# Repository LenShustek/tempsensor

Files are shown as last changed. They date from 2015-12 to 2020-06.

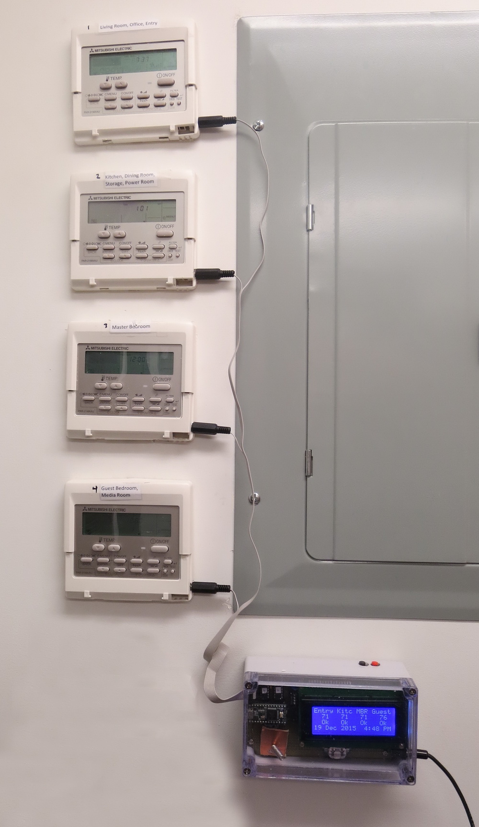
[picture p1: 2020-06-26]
temprcvr_V2/complete_installation.JPG

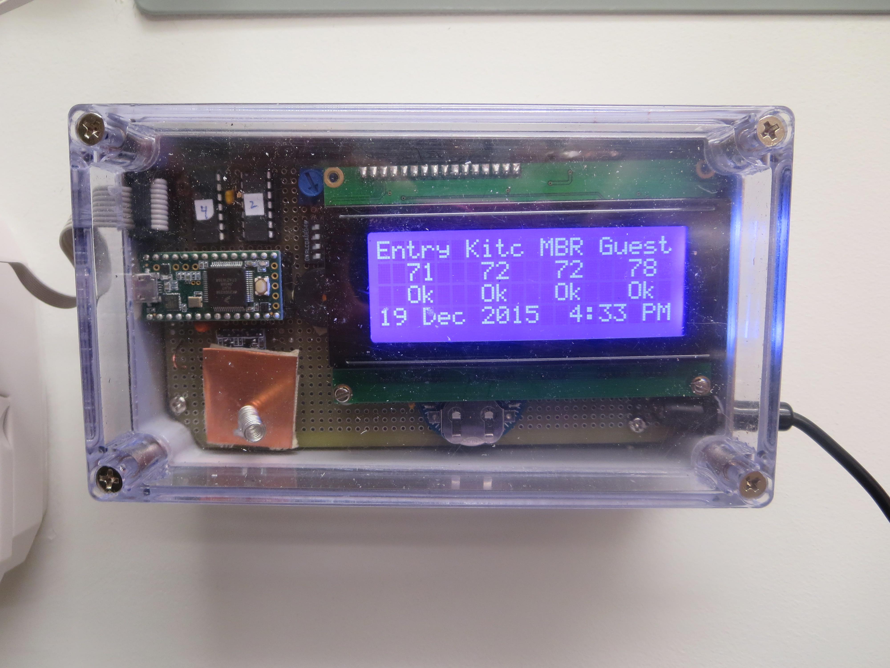
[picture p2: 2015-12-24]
[Originals]/receiver_box_02.JPG

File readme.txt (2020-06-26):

This project consists of four small battery-powered remote wireless temperature sensors, and a single wall-powered receiver for them that replaces the temperature-monitoring thermistors inside wall-mounted thermostats.

My motivation: we have a four-zone Mitsubishi/Honeywell MNET-based HVAC system that was incorrectly designed without temperature monitoring in the zones. We want to avoid breaking walls and ceilings to wire compatible themostats. The Honeywell C7189 wireless indoor remote temperature sensor is not compatible, and we don't like the complicated Mitsubishi MRCH1 wireless remote controller because it's big, ugly, and conflicts with the automation system (Control4) that is supposed to be in control of all the HVAC zones.

This project reinstates the four centrally located wired wall-mounted PAR-21MAA thermostats that were part of the original design, but replaces their temperature-sensing thermistors with resistances generated by "digital potentiometers" controlled by an Arduino-like microprocessor. The wireless remote temperature sensors send periodic wireless packets to the central receiver. The indoor range is several hundred feet.

The first version of the system -- which used an LCD display, the Seeed HC-12 433 Mhz transceiver, and a Teensy LC processor -- was installed in December 2015 and worked well for years. The only annoying issue was that with the best low-power code I could muster, the lifetime of the three AAA batteries in each temperature sensor was only 2-3 months.

That prompted me to make a second version of the temperature sensor that uses an e-Paper display, a HopeRF LoRa 868/915 Mhz transceiver, and a bare ATMega328 processor. The average power utilization is now below 100 uA, which resulted in battery life of well over a year.

Unfortunately Waveshare decided to redesign their e-paper module to be 5V compatible, and the resulting quiescent power drain from the voltage regulator and level shifters destroys the "zero current when sleeping" feature that made me choose e-paper displays in the first place. In addition, some of their older modules are defective and use 100 mA when updating the display instead of the specified 12 mA maximum, which puts battery life back to months, not years. 

That prompted me to make a third version that uses just the raw e-paper display, not the module. It was also an opportunity to exercise my newly-learned skills of designing and fabricating boards with only surface-mount components. The average power utilization is now about 60 uA, so the batteries last almost two years.

Len Shustek
Nov 2015, Jul 2018, Jun 2020

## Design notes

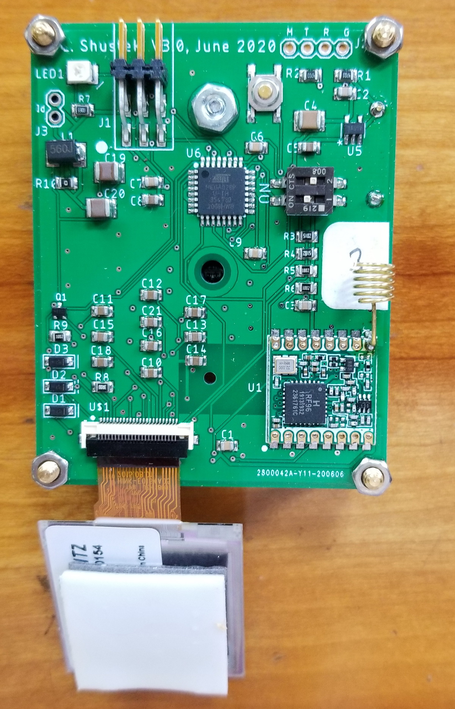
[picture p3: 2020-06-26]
tempsensor_V3/inside.jpg

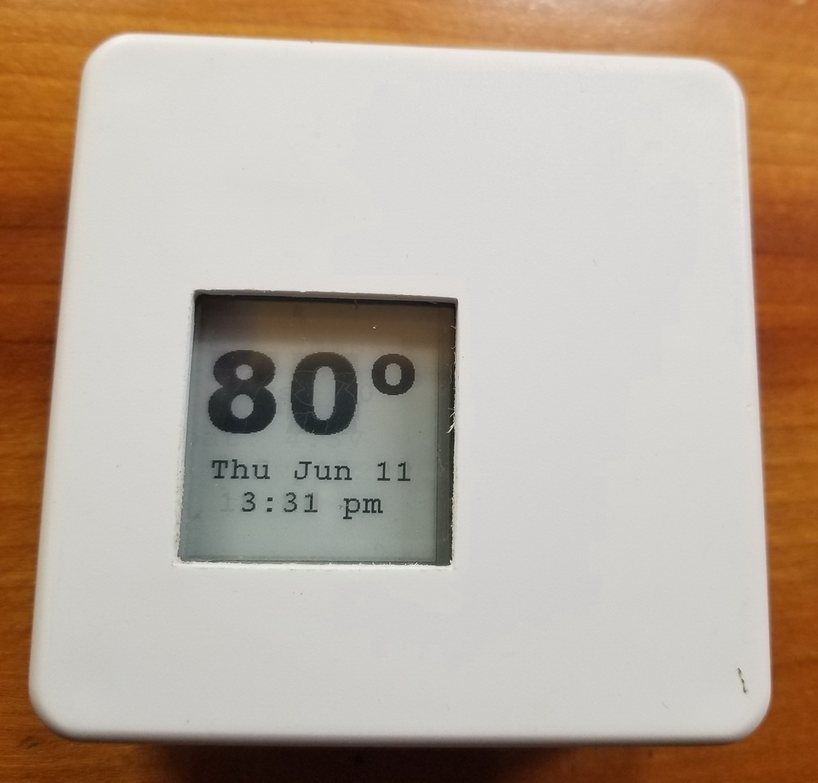
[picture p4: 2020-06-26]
tempsensor_V3/outside.jpg

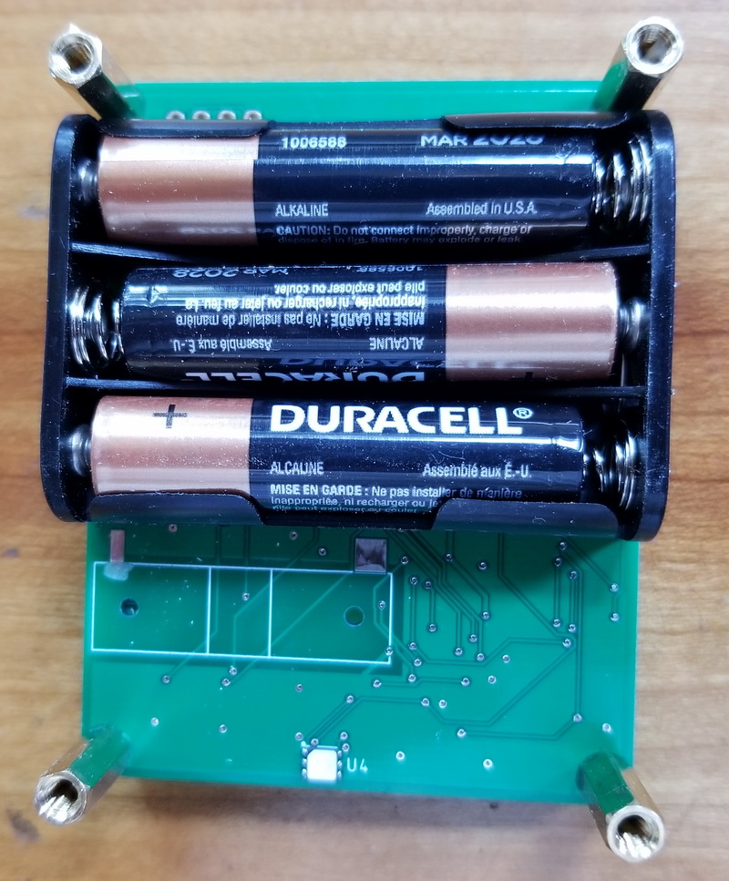
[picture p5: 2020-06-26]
tempsensor_V3/bottom.jpg

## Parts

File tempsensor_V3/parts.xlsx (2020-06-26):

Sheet: parts
 |  | Tempsensor V3.0 parts
# per unit | # for all units | have | order | descr | for | ref | manuf | manuf p/n | vendor | vendor p/n | price each
1 | 5 | 4 |  | 4xAAA battery holder |  | B1 | Keystone | 2479 | Mouser | 534-2479 | $1.61
5 | 25 |  | 100 | 0.1 ufd 50V X7R SMD 0805 capacitor |  | C1,C2,C3,C7,C9 | Kemet | C0805C104K5RACTU | Mouser | 80-C0805C104K5R | $0.06
1 | 5 |  | 10 | 4.7 ufd 50V X7R SMD 1210 capacitor |  | C19 | Kemet | C1210C475K5RAC | Mouser | 80-C1210C475K5RAC | $0.48
1 | 5 | 5 | 10 | 10 ufd 25V X7R SMD 1210 capacitor |  | C20 | Kemet | C1210C106M3RACTU | Mouser | 80-C1210C106M3R | $0.39
1 | 5 |  | 10 | 2.2 ufd 50V X7R SMD 1210 capacitor |  | C4 | Kemet | C1210C225K5RACTU | Mouser | 80-C1210C225K5R | $0.45
12 | 60 |  | 100 | 1.0 ufd 50V X7R SMD 0805 capacitor |  | C5,C8,C10-18,C21 | Kemet | C0805C105K5RACTU | Mouser | 80-C0805C105K5R | $0.17
1 | 5 |  | 100 | .047ufd 50V SMD 0805 capacitor |  | C6 | Kemet | C0805C473K5RACTU | Mouser | 80-C0805C473K5R | $0.06
3 | 15 |  | 100 | MBR0530 Schottky diode |  | D1,D2,D3 | ON Semi | MBR0530T1G | Mouser | 863-MBR0530T1G | $0.08
~~1~~ | ~~5~~ |  | ~~20~~ | ~~2x6 SMD pin header 0.1" vertical~~ | ~~programming~~ | ~~J1~~ | ~~molex~~ | ~~15-91-0060~~ | ~~Mouser~~ | ~~538-15-91-0060~~ | ~~$0.35~~
1 | 5 |  | 10 | 2x6 SMD pin header 0.1" rt angle | programming | J2 | Samtec | TSM-103-01-S-DH-TR TSM-103-01-L-DH | Mouser Digikey | 200-TSM10301SDHTR SAM9026-ND | 1.48 0.88
1 | 5 | lots |  | 1x3 through hole pin header 0.1" | debugging | J2
1 | 5 | 18 |  | 56 uH inductor SMD 1812 | filter | L1 | Bourns | PM1812-560J-RC | Mouser | 542-PM1812-560J-RC | $0.31
1 | 5 |  | 25 | red LED, SMD PLCC-2, flat top, 2mm high |  | LED1 | OSRAM | LS T67F-T2V2-1-1-Z | Mouser | 720-LST67FT2V211Z | $0.27
1 | 5 |  | 25 | Si1308 N-channel MOSFET |  | Q1 | Vishay | SI1308EDL-T1-GE3 | Mouser Digikey | 78-SI1308EDL-T1-GE3 SI1308EDL-T1-GE3CT-ND | $0.45
2 | 10 | some |  | 470K 1% 1/8W SMD 0805 resistor |  | R1,R2
2 | 10 | some |  | 51K 1% 1/8W SMD 0805 resistor |  | R3,R4
3 | 15 | some |  | 10K 1% 1/8W SMD 0805 resistor |  | R5,R6,R9
1 | 5 | some |  | 330 ohm 1% 1/8W SMD 0805 resistor |  | R7
1 | 5 | some |  | 3 ohm 1% 1/8W SMD 0805 resistor |  | R8
1 | 5 |  | 10 | 2-position SPST slide switch, gull wing SMD | node address | SW2 | CTS | 219-2MSTRF | Mouser | 774-2192MSTRF | $0.62
1 | 5 |  | 10 | FPC connector, 24-pin, SMD, bottom contact |  | U$1 | Molex | 505110-2491 | Mouser | 538-505110-2491 | $0.71
1 | 5 |  | 2 | RFM95 RF 868 Mz radio transceiver |  | U1 | Seeed | 109990166 | Seeed Digikey | 109990166 1597-1488-ND | 6.95 7.09
1 | 5 |  | 5 | Si7021-A20 temperature/humidity sensor |  | U4 | Silicon Labs | SI7021-A20-IM1 | Mouser | 634-SI7021-A20-IM1 | $3.53
1 | 5 | 13 |  | MCP1711 3.3V voltage regulator |  | U5 | Microchip | MCP1711T-33I/OT | Mouser | 579-MCP1711T-33I/OT | $0.37
1 | 5 | 2 | 10 | ATMega328P processor, SMD TQFP-44 |  | U6 | Microchip | ATMEGA328P-AUR | Mouser Digikey | 556-ATMEGA328P-AUR ATMEGA328P-AURCT-ND | $1.73
1 | 5 |  | 5 | 1.54" e-paper B/W display |  |  | Crystalfonz Waveshare | CFAP200200A1-0154 1`2955 | Crystalfonz Waveshare |  | 12.64 12.99 | https://www.amazon.com/Waveshare-Resolution-Electronic-Controller-Interface/dp/B071HW4Z6N
1 | 5 |  | 5 | 868 Mhz helical antenna |  |  | PulseLarsen Ants | W3136 | Digikey | 1837-1134-2-ND | $1.36
1 | 5 |  | 25 | pushbutton, SPST mom, gullwing SMT |  |  | C&K | PTS525SM15SMTR2 LFS | Digikey | CKN9104CT-ND | $0.32
5 | units to build

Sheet: total current
8 | 0.071
8.002 | 0.051
8.004 | 0.031
8.006 | -0.009
8.008 | 0.071
8.01 | 0.011
8.012 | -0.009
8.014 | 0.051
8.016 | 0.011
8.018 | 0.051
8.02 | 0.051
8.022 | 0.031
8.024 | 0.051
8.026 | 0.031
8.028 | 0.031
8.03 | 0.051
8.032 | 0.011
8.034 | 0.091
8.036 | 1.491
8.038 | 0.591
8.04 | 0.871
8.042 | 0.981
8.044 | 1.001
8.046 | 0.921
8.048 | 0.961
8.05 | 0.961
8.052 | 0.961
8.054 | 1.041
8.056 | 0.921
8.058 | 0.921
8.06 | 0.921
8.062 | 0.981
8.064 | 0.961
8.066 | 0.961
8.068 | 0.921
8.07 | 0.961
8.072 | 1.021
8.074 | 1.861
8.076 | 19.521
8.078 | 17.461
8.08 | 16.921
8.082 | 16.591
8.084 | 16.221
8.086 | 15.961
8.088 | 15.591
8.09 | 15.361
8.092 | 15.281
8.094 | 14.991
8.096 | 14.871
8.098 | 14.541
8.1 | 14.501
8.102 | 14.451
8.104 | 22.831
8.106 | 22.191
8.108 | 22.011
8.11 | 21.451
8.112 | 21.101
8.114 | 20.751
8.116 | 20.501
8.118 | 20.321
8.12 | 20.071
8.122 | 2.851
8.124 | 1.991
8.126 | 2.751
8.128 | 2.011
8.13 | 2.871
8.132 | 2.811
8.134 | 1.641
8.136 | 1.611
8.138 | 1.371
8.14 | 2.131
8.142 | 0.941
8.144 | 1.991
8.146 | 2.831
8.148 | 3.061
8.15 | 3.121
8.152 | 2.231
8.154 | 3.801
8.156 | 2.731
8.158 | 3.181
8.16 | 3.161
8.162 | 2.641
8.164 | 4.081
8.166 | 3.201
8.168 | 2.071
8.17 | 2.051
8.172 | 3.011
8.174 | 2.771
8.176 | 2.731
8.178 | 2.771
8.18 | 2.151
8.182 | 3.491
8.184 | 1.821
8.186 | 2.171
8.188 | 2.641
8.19 | 2.641
8.192 | 2.731
8.194 | 4.371
8.196 | 2.501
8.198 | 3.511
8.2 | 2.311
8.202 | 1.861
8.204 | 3.801
8.206 | 4.451
8.208 | 2.831
8.21 | 2.071
8.212 | 2.811
8.214 | 2.461
8.216 | 3.471
8.218 | 3.381
8.22 | 3.061
8.222 | 4.191
8.224 | 3.571
8.226 | 3.921
8.228 | 2.401
8.23 | 2.931
8.232 | 1.451
8.234 | 2.151
8.236 | 2.971
8.238 | 2.851
8.24 | 3.861
8.242 | 0.831
8.244 | 4.171
8.246 | 2.991
8.248 | 2.291
8.25 | 2.561
8.252 | 3.341
8.254 | 3.451
8.256 | 0.261
8.258 | 2.361
8.26 | 2.681
8.262 | 3.181
8.264 | 2.601
8.266 | 3.061
8.268 | 3.411
8.27 | 1.681
8.272 | 2.031
8.274 | 1.491
8.276 | 1.781
8.278 | 2.911
8.28 | 3.511
8.282 | 4.131
8.284 | 2.601
8.286 | 4.151
8.288 | 3.201
8.29 | 3.631
8.292 | 3.181
8.294 | 2.441
8.296 | 3.571
8.298 | 3.141
8.3 | 3.321
8.302 | 5.011
8.304 | 2.361
8.306 | 2.341
8.308 | 2.991
8.31 | 2.851
8.312 | 3.061
8.314 | 1.901
8.316 | 2.231
8.318 | 2.681
8.32 | 2.621
8.322 | 2.731
8.324 | 3.361
8.326 | 2.621
8.328 | 0.301
8.33 | 3.141
8.332 | 3.221
8.334 | 2.541
8.336 | 2.641
8.338 | 3.881
8.34 | 2.311
8.342 | 2.111
8.344 | 3.141
8.346 | 2.171
8.348 | 2.731
8.35 | 4.131
8.352 | 3.301
8.354 | 4.641
8.356 | 3.281
8.358 | 4.391
8.36 | 1.881
8.362 | 3.011
8.364 | 2.561
8.366 | 2.481
8.368 | 3.861
8.37 | 1.821
8.372 | 3.671
8.374 | 2.971
8.376 | 2.641
8.378 | 2.601
8.38 | 2.771
8.382 | 2.561
8.384 | 1.271
8.386 | 1.941
8.388 | 3.591
8.39 | 2.621
8.392 | 3.801
8.394 | 3.081
8.396 | 2.871
8.398 | 1.451
8.4 | 1.551
8.402 | 3.431
8.404 | 3.341
8.406 | 2.421
8.408 | 2.441
8.41 | 3.491
8.412 | 2.731
8.414 | 3.181
8.416 | 2.231
8.418 | 2.641
8.42 | 3.141
8.422 | 3.201
8.424 | 2.521
8.426 | 3.011
8.428 | 5.071
8.43 | 0.671
8.432 | 0.921
8.434 | 0.871
8.436 | 1.861
8.438 | 1.061
8.44 | 1.081
8.442 | 0.541
8.444 | 0.051
8.446 | 3.201
8.448 | 0.461
8.45 | 1.201
8.452 | 0.921
8.454 | 1.161
8.456 | 1.331
8.458 | 0.011
8.46 | 0.011
8.462 | 0.031
8.464 | 0.051
8.466 | 0.011
8.468 | -0.009
8.47 | 0.031
8.472 | 0.051
8.474 | -0.009
8.476 | 0.031
8.478 | -0.009
8.48 | -0.009
8.482 | 0.031
8.484 | 0.011
8.486 | 0.011
8.488 | -0.009
8.49 | -0.009
8.492 | 0.011
8.494 | -0.009
8.496 | 0.011
8.498 | 0.051

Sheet: epaper displays
1.54" e-paper modules
 |  |  |  | in stock | delivery
MikroElektronika | MIKROE-3157 | Digikey | 1471-2067-ND | 9 | 1 week | $20.79
Waveshare |  | Amazon | B071HW4Z6N | ? | 6 weeks | $12.99
CystalFontz | CFAP200200A1-0154 | CystalFontz |  | ? | 1 week | $12.64
Pervasive Displays | E2154CS091 | Digikey | E2154CS091-ND | 346 | 1 week | $6.80 | short tab

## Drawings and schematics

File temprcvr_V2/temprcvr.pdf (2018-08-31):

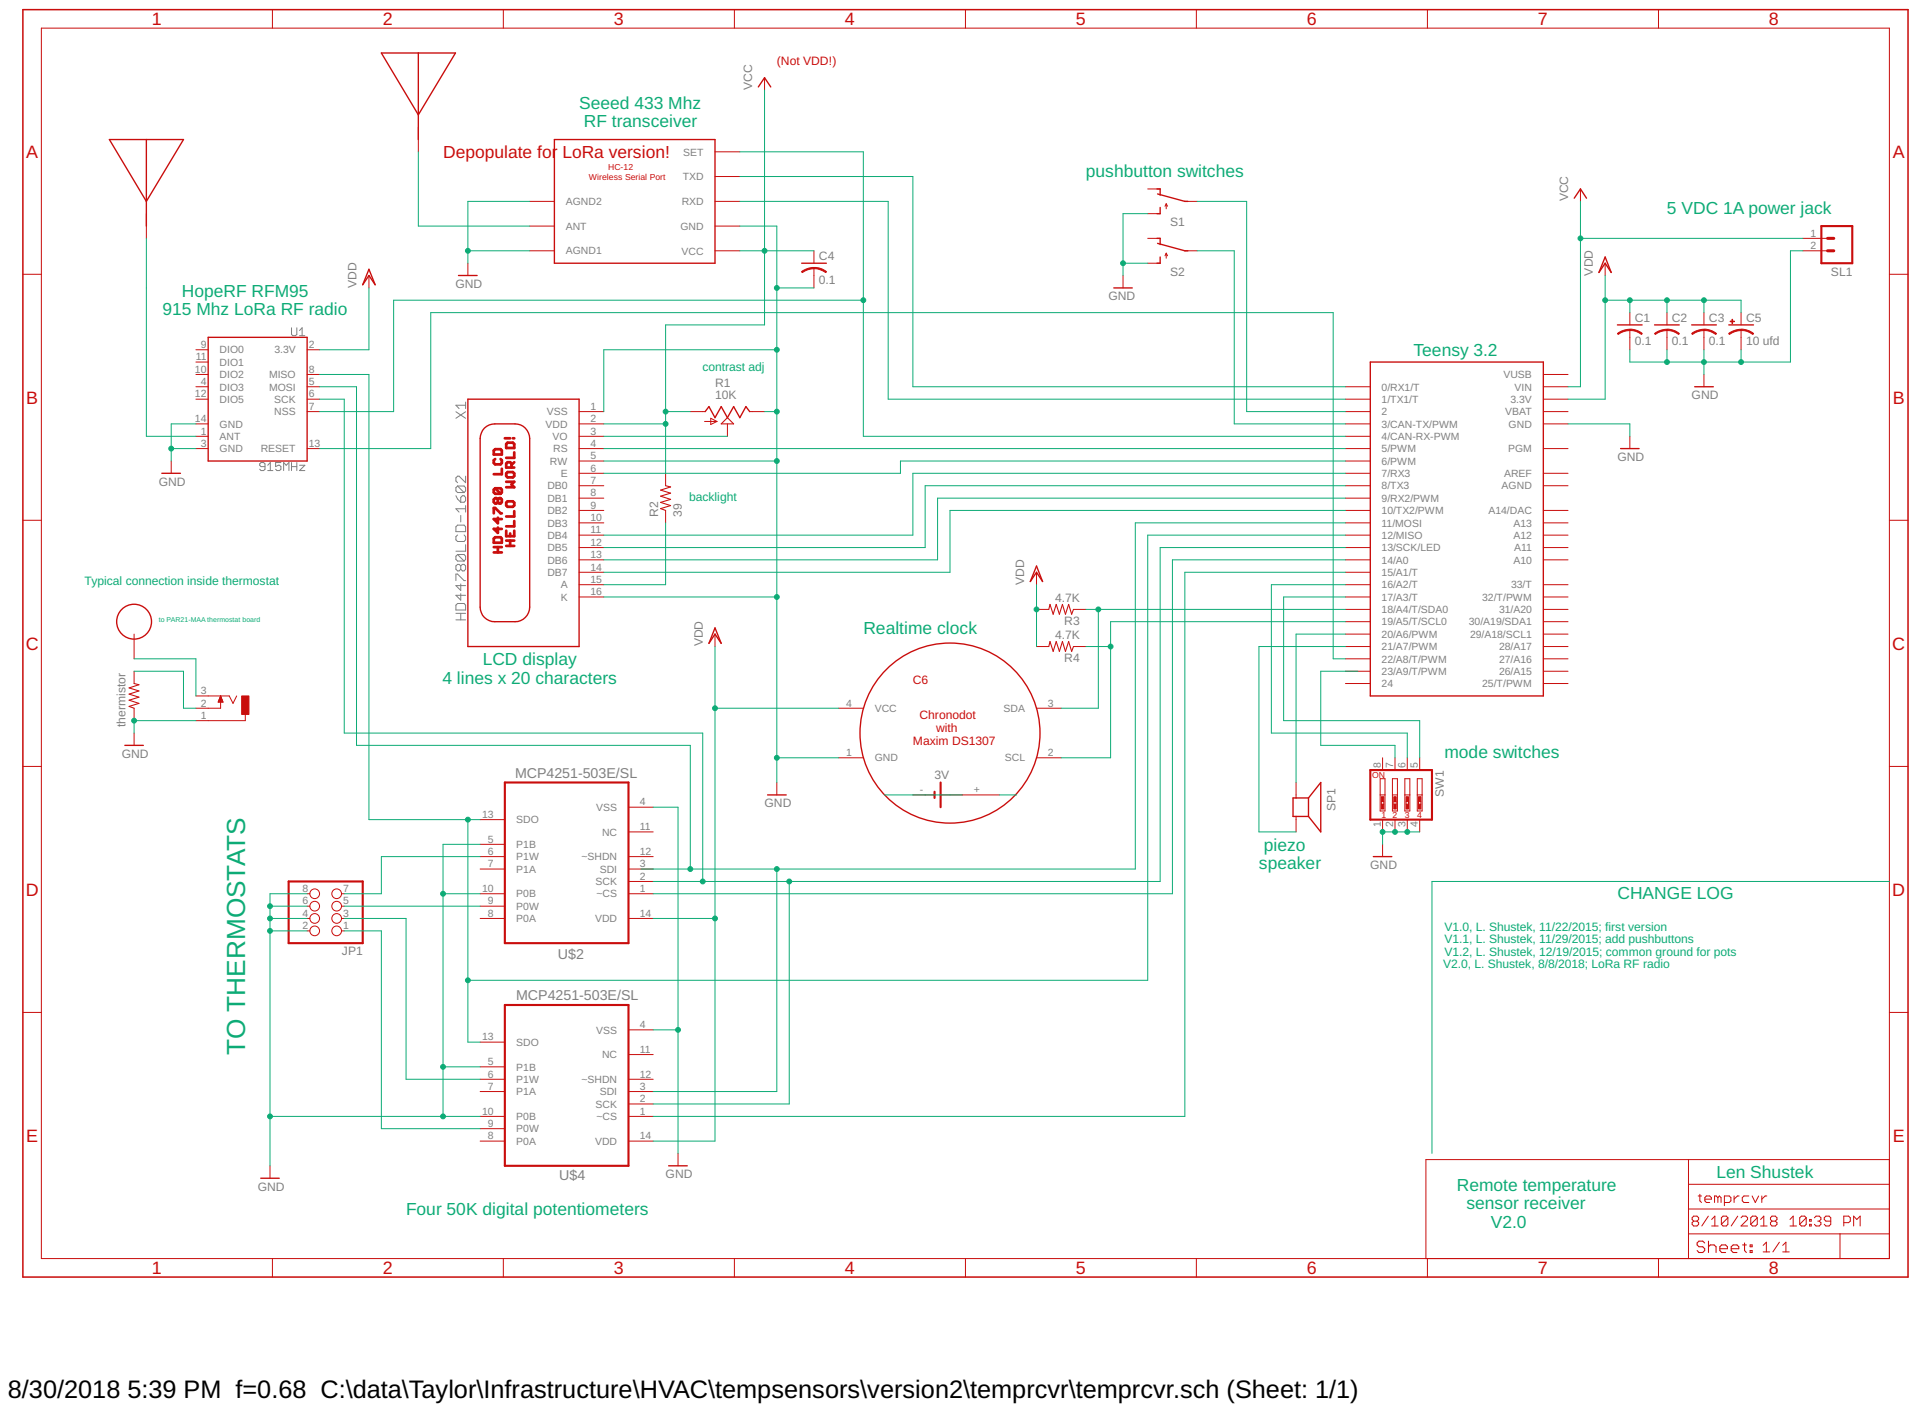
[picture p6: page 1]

Seeed 433 Mhz RF transceiver

Depopulate for LoRa version! HC-12 Wireless Serial Port A

HopeRF RFM95
915 Mhz LoRa RF radio

12 DB4
13 DB5
14 DB6
15 DB7

to PAR21-MAA thermostat board Typical connection inside thermostat

1 2 3 4 ON Chronodot with Maxim DS1307 C6

V1.0, L. Shustek, 11/22/2015; first version
V1.1, L. Shustek, 11/29/2015; add pushbuttons V1.2, L. Shustek, 12/19/2015; common ground for pots

V2.0, L. Shustek, 8/8/2018; LoRa RF radio

8/30/2018 5:39 PM f=0.68 C:\data\Taylor\Infrastructure\HVAC\tempsensors\version2\temprcvr\temprcvr.sch (Sheet: 1/1)

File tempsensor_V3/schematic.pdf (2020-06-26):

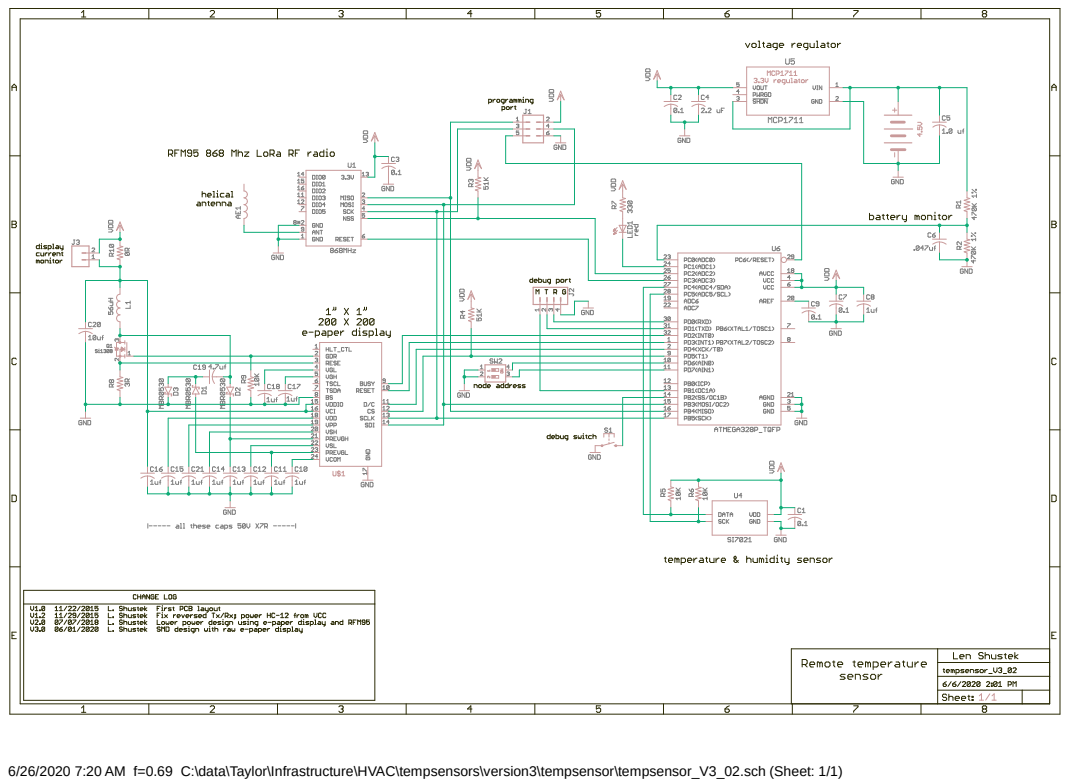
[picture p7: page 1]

6/26/2020 7:20 AM f=0.69 C:\data\Taylor\Infrastructure\HVAC\tempsensors\version3\tempsensor\tempsensor_V3_02.sch (Sheet: 1/1)

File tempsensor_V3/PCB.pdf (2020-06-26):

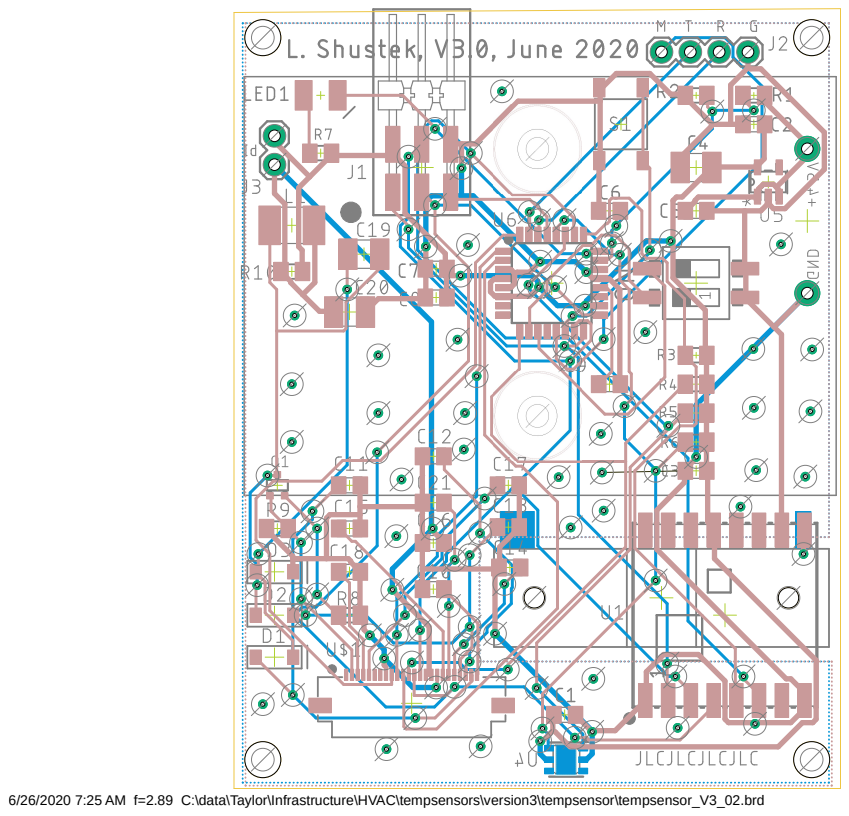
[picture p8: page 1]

6/26/2020 7:25 AM f=2.89 C:\data\Taylor\Infrastructure\HVAC\tempsensors\version3\tempsensor\tempsensor_V3_02.brd

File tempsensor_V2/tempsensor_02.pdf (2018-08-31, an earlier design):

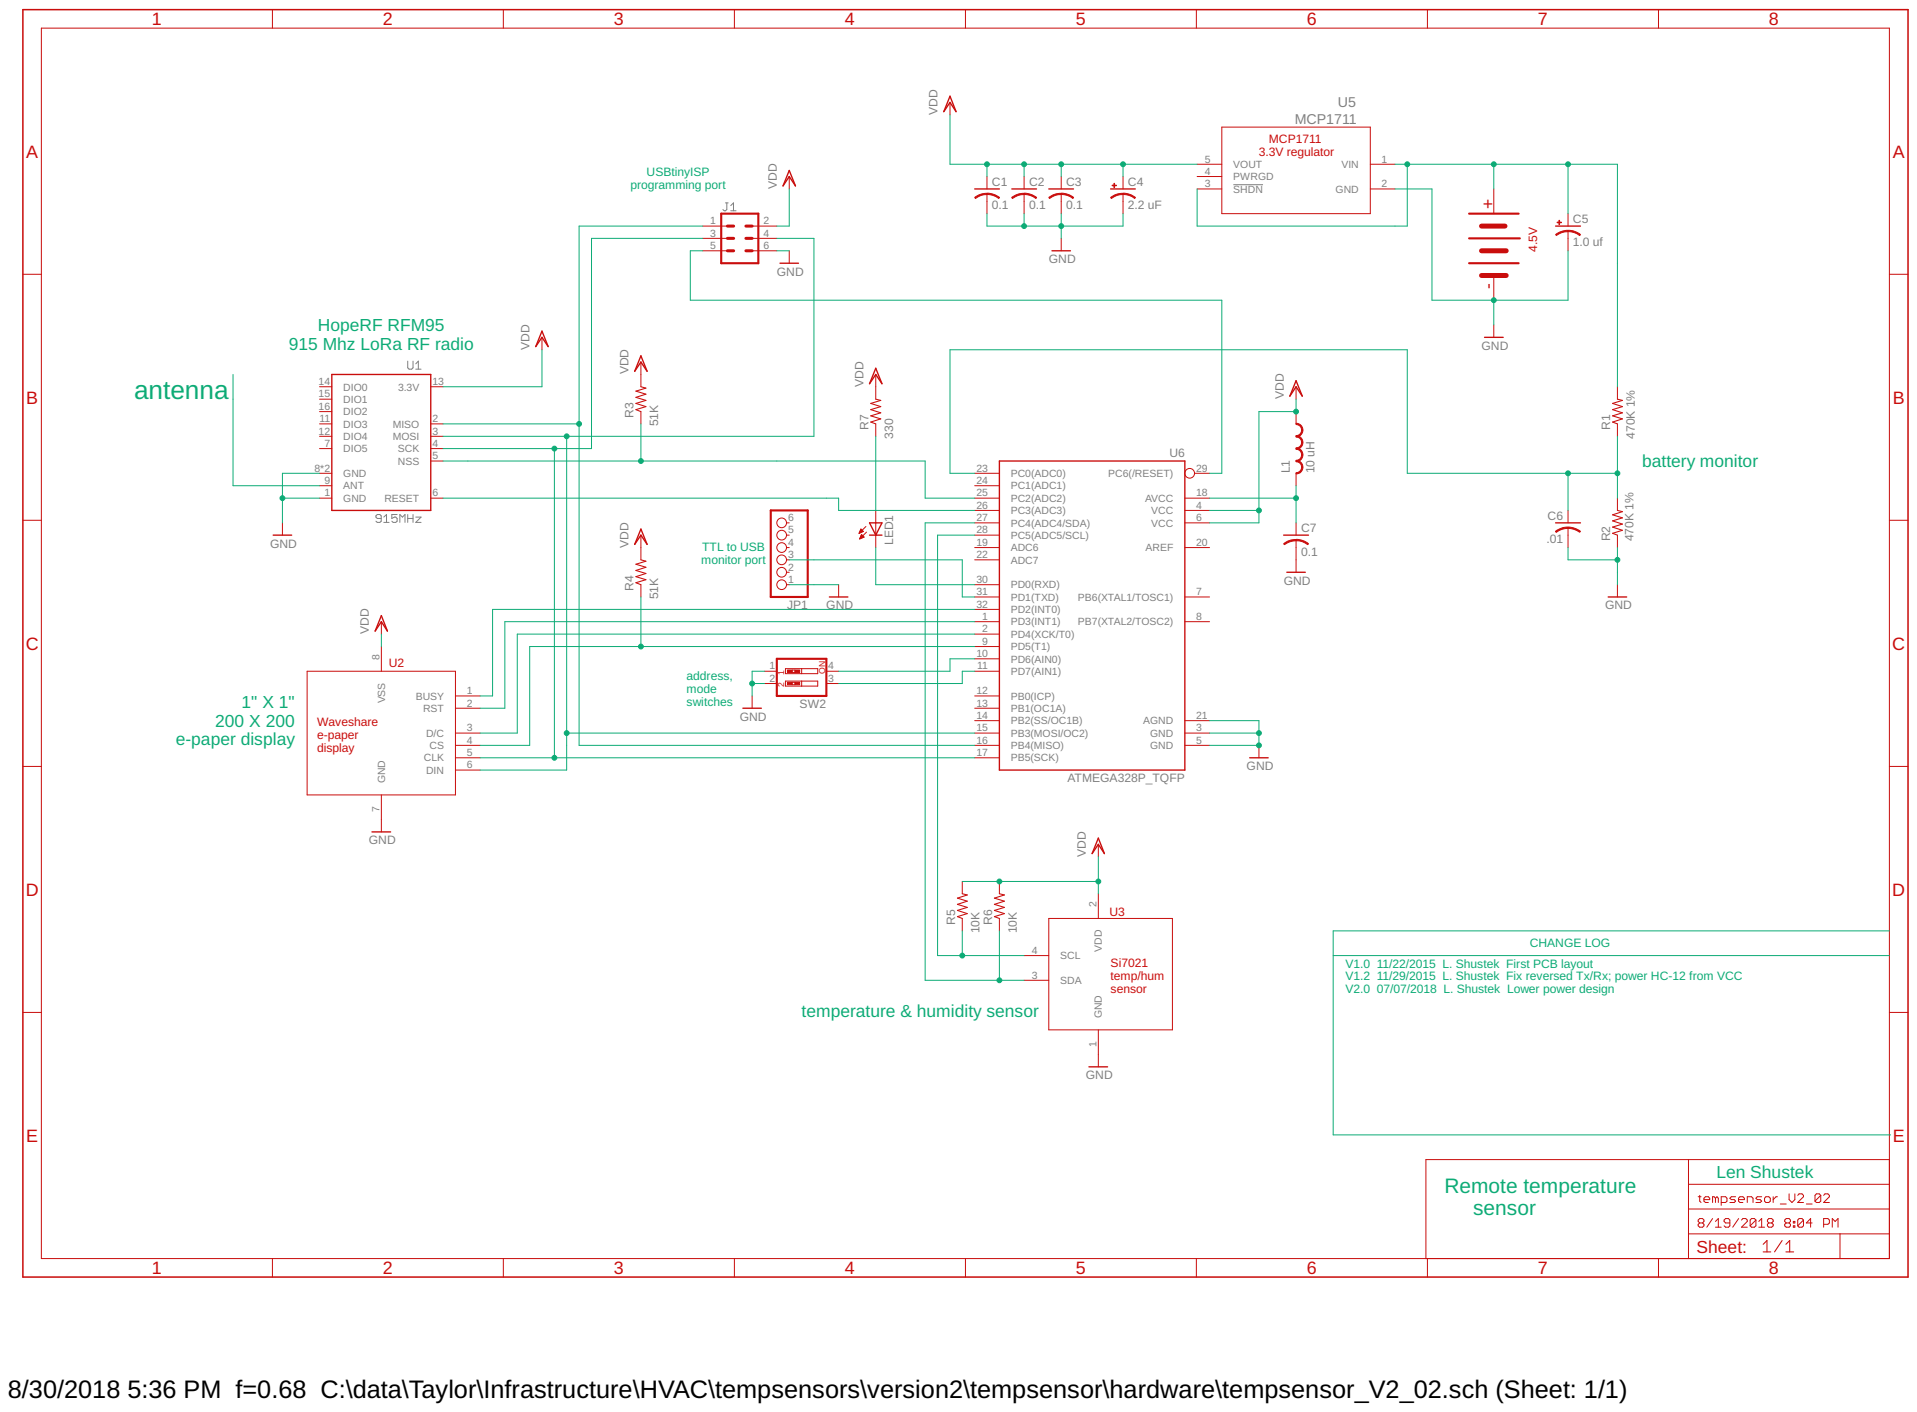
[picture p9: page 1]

HopeRF RFM95
915 Mhz LoRa RF radio

TTL to USB monitor port

4 D/C | | 3 GND 5

5 CS | PB5(SCK) 17
6 CLK

V1.0 11/22/2015 L. Shustek First PCB layout CHANGE LOG

V1.2 11/29/2015 L. Shustek Fix reversed Tx/Rx; power HC-12 from VCC
V2.0 07/07/2018 L. Shustek Lower power design

8/30/2018 5:36 PM f=0.68 C:\data\Taylor\Infrastructure\HVAC\tempsensors\version2\tempsensor\hardware\tempsensor_V2_02.sch (Sheet: 1/1)

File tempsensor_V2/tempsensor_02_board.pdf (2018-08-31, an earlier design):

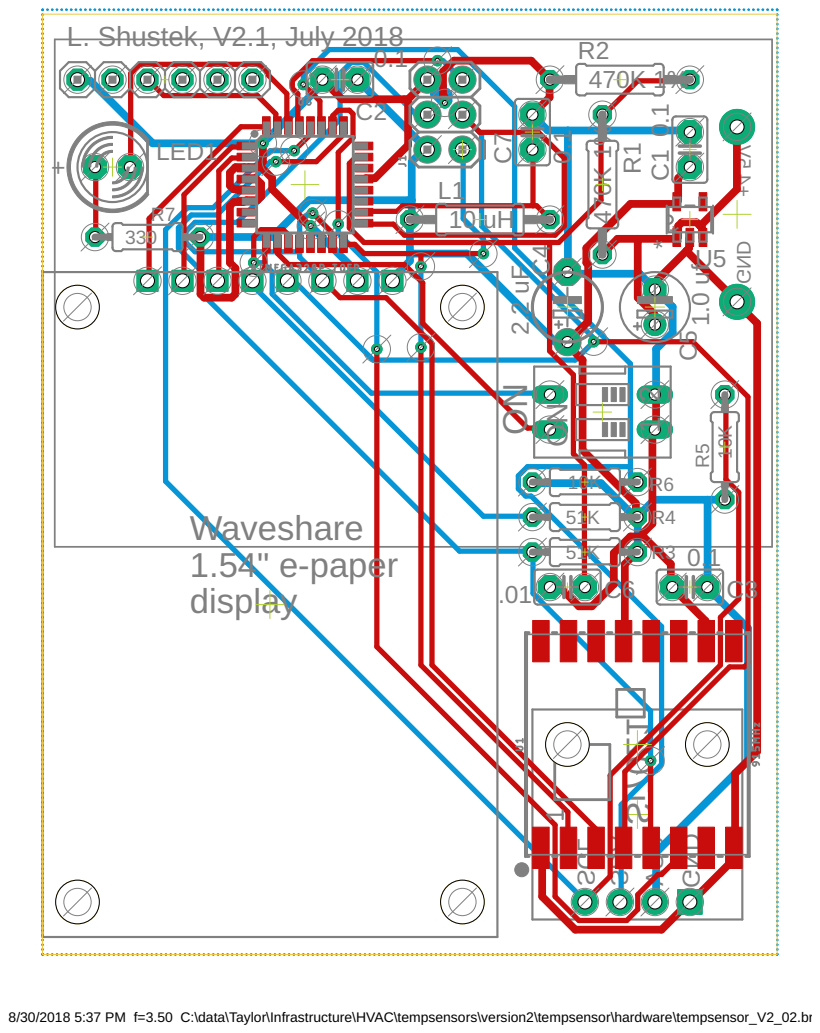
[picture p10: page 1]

8/30/2018 5:37 PM f=3.50 C:\data\Taylor\Infrastructure\HVAC\tempsensors\version2\tempsensor\hardware\tempsensor_V2_02.brd

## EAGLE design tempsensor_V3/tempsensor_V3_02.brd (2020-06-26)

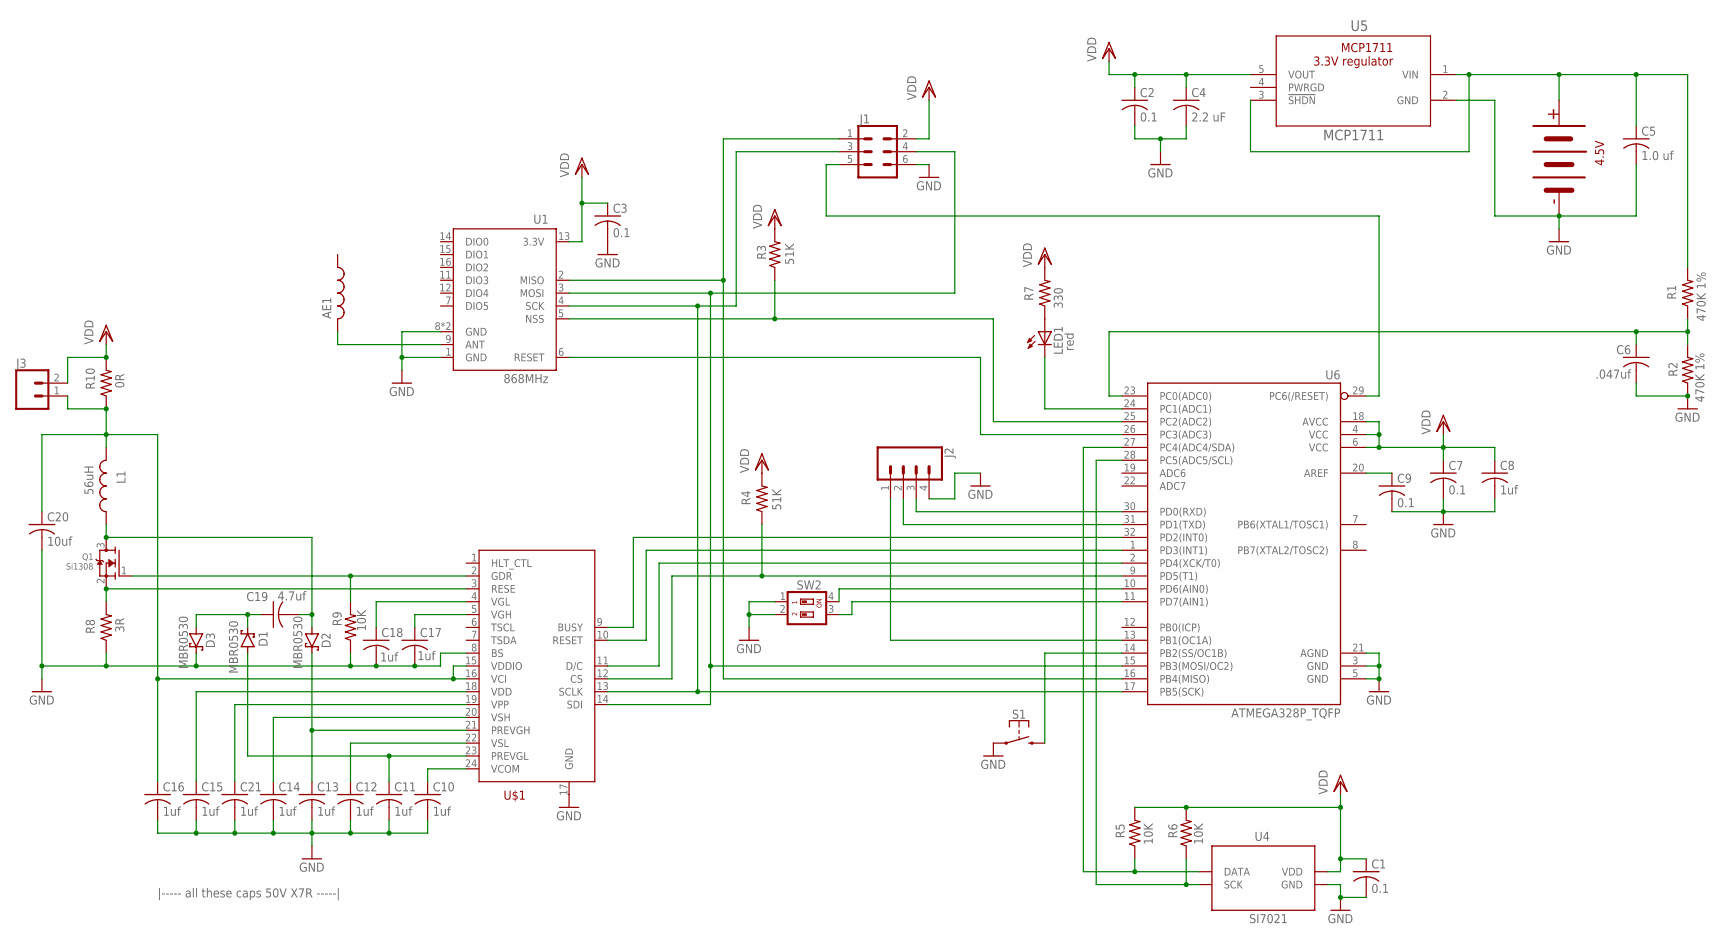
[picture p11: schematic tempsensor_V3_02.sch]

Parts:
AE1: ANTENNA-HELICAL; ANTENNA-HELICAL_PULSE_SMD
B1: 3PC-BATTERY-HOLDER; 3AAA-BATTERY-HOLDER
C1, C2, C3, C7, C9: 0.1; C0805
C4: 2.2 uF; C1210
C5: 1.0 uf; C0805
C6: .047uf; C0805
C8, C10, C11, C12, C13, C14, C15, C16, C17, C18, C21: 1uf; C0805
C19: 4.7uf; C1210
C20: 10uf; C1210
D1, D2, D3: MBR0530; SOD123-2
J1: CONN_2X3; 2X3_SMT_RTANGLE_OUTLINE
J2: CONN_04; 1X04
J3: CONN_02; 1X02
L1: 56uH; L1812
LED1: red; LED_PLCC-2
Q1: Si1308; SC70-3-R
R1, R2: 470K 1%; M0805
R3, R4: 51K; M0805
R5, R6, R9: 10K; M0805
R7: 330; M0805
R8: 3R; M0805
R10: 0R; M0805
S1: PUSHBUTTON-SPSTSWITCH_C&K_GULLWING_5MM; SWITCH_C&K_GULLWING_5MM
SW2: SWITCH-2POS-DIP; SMS-002
U1: 868MHz; RFM69HCW-XXXS2
U4: SI7021; DFN-6-3X3-SI7021
U5: MCP1711; SOT-23-5
U6: ATMEGA328P_TQFP; TQFP32-08
U$1: E-PAPER-DISPLAYMOLEX; MOLEX_50511

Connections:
GND: B1.P$1, C1.2, C2.2, C3.2, C4.2, C5.2, C6.2, C7.2, C8.2, C9.2, C10.2, C11.2, C12.2, C13.2, C14.2, C15.2, C16.2, C17.2, C18.2, C20.2, C21.2, D3.P$2 (C), J1.6, J2.4, R2.1, R8.1, R9.1, S1.P$1 (1), S1.P$2 (1), SW2.1, SW2.2, U1.1 (GND), U1.8 (GND), U1.10 (GND), U4.GND, U5.2 (GND), U6.3 (GND), U6.5 (GND), U6.21 (AGND), U$1.8 (BS), U$1.17 (GND)
unnamed: R6.1, U4.SCK, U6.28 (PC5(ADC5/SCL))
unnamed: R5.1, U4.DATA, U6.27 (PC4(ADC4/SDA))
unnamed: J1.4, U1.3 (MOSI), U6.15 (PB3(MOSI/OC2)), U$1.14 (SDI)
unnamed: J1.1, U1.2 (MISO), U6.16 (PB4(MISO))
unnamed: J1.3, U1.4 (SCK), U6.17 (PB5(SCK)), U$1.13 (SCLK)
unnamed: U1.6 (RESET), U6.26 (PC3(ADC3))
unnamed: R3.1, U1.5 (NSS), U6.25 (PC2(ADC2))
unnamed: U6.32 (PD2(INT0)), U$1.9 (BUSY)
unnamed: U6.1 (PD3(INT1)), U$1.10 (RESET)
unnamed: U6.2 (PD4(XCK/T0)), U$1.11 (D/C)
unnamed: R4.1, U6.9 (PD5(T1)), U$1.12 (CS)
unnamed: J2.2, U6.31 (PD1(TXD))
unnamed: LED1.P$2 (C), U6.24 (PC1(ADC1))
unnamed: LED1.P$1 (A), R7.1
unnamed: SW2.4, U6.10 (PD6(AIN0))
unnamed: SW2.3, U6.11 (PD7(AIN1))
unnamed: B1.P$2, C5.1, R1.2, U5.1 (VIN), U5.3 (!SHDN)
unnamed: C9.1, U6.20 (AREF)
unnamed: AE1.P$1, U1.9 (ANT)
unnamed: J1.5, U6.29 (PC6(/RESET))
unnamed: C10.1, U$1.24 (VCOM)
unnamed: C11.1, D1.P$1 (A), U$1.23 (PREVGL)
unnamed: C12.1, U$1.22 (VSL)
unnamed: C13.1, D2.P$2 (C), U$1.21 (PREVGH)
unnamed: C14.1, U$1.20 (VSH)
unnamed: C16.1, C20.1, J3.1, L1.2, R10.1, U$1.15 (VDDIO), U$1.16 (VCI)
unnamed: C6.1, R1.1, R2.2, U6.23 (PC0(ADC0))
unnamed: C15.1, U$1.18 (VDD)
unnamed: C21.1, U$1.19 (VPP)
unnamed: C17.1, U$1.5 (VGH)
unnamed: J2.1, U6.13 (PB1(OC1A))
unnamed: C18.1, U$1.4 (VGL)
unnamed: C19.2, D2.P$1 (A), L1.1, Q1.3 (D)
unnamed: C19.1, D1.P$2 (C), D3.P$1 (A)
unnamed: Q1.1 (G), R9.2, U$1.2 (GDR)
unnamed: Q1.2 (S), R8.2, U$1.3 (RESE)
unnamed: J2.3, U6.30 (PD0(RXD))
unnamed: S1.P$3 (3), S1.P$4 (3), U6.14 (PB2(SS/OC1B))
PWRGD: U5.4 (PWRGD)
VDD: C1.1, C2.1, C3.1, C4.1, C7.1, C8.1, J1.2, J3.2, R3.2, R4.2, R5.2, R6.2, R7.2, R10.2, U1.13 (3.3V), U4.VDD, U5.5 (VOUT), U6.4 (VCC), U6.6 (VCC), U6.18 (AVCC)

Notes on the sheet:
|----- all these caps 50V X7R -----|

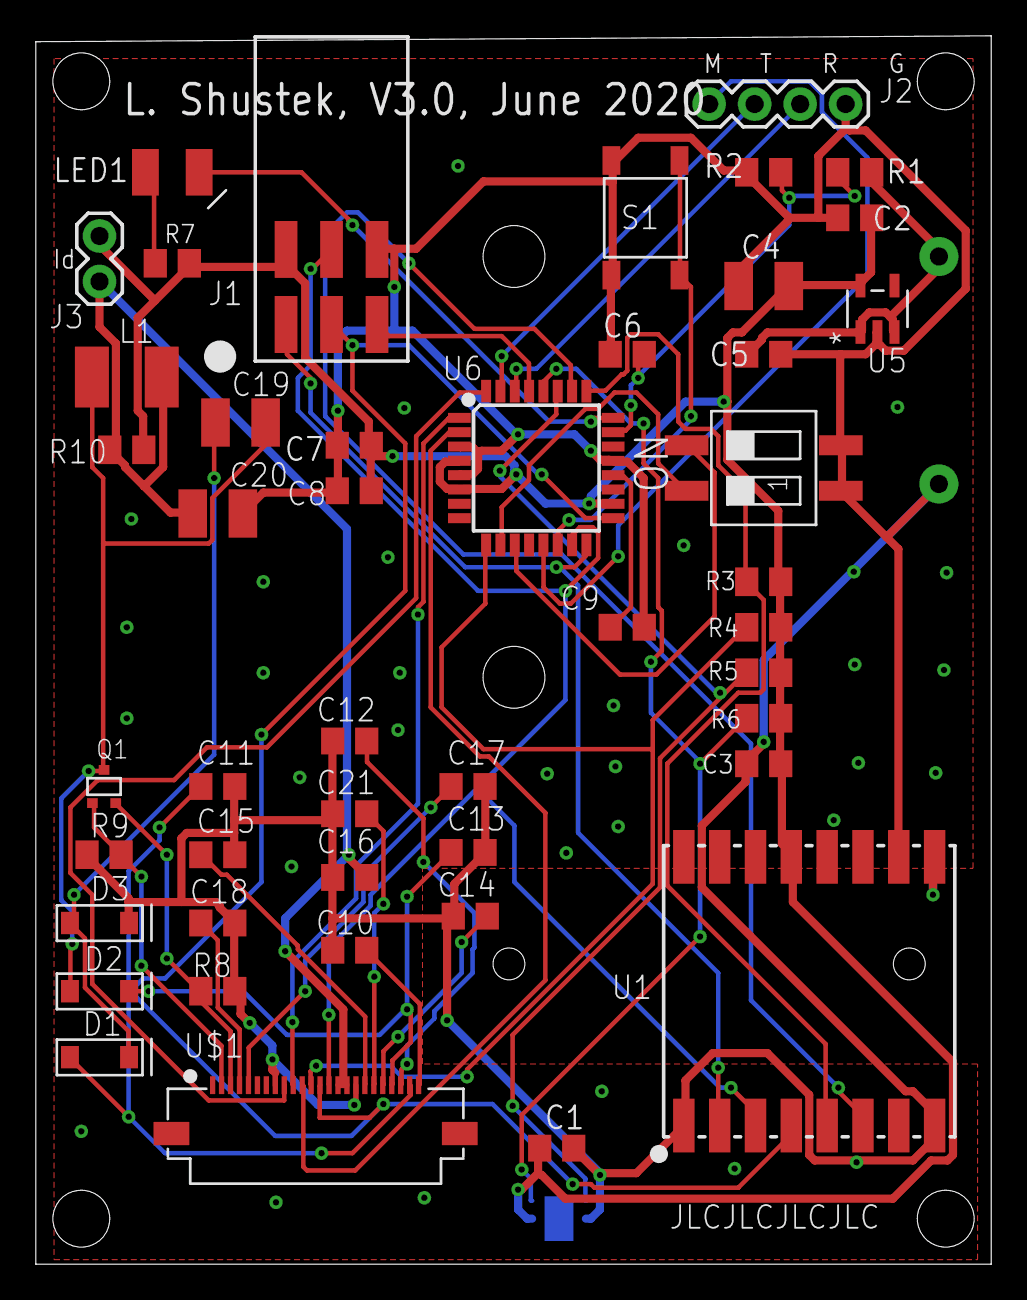
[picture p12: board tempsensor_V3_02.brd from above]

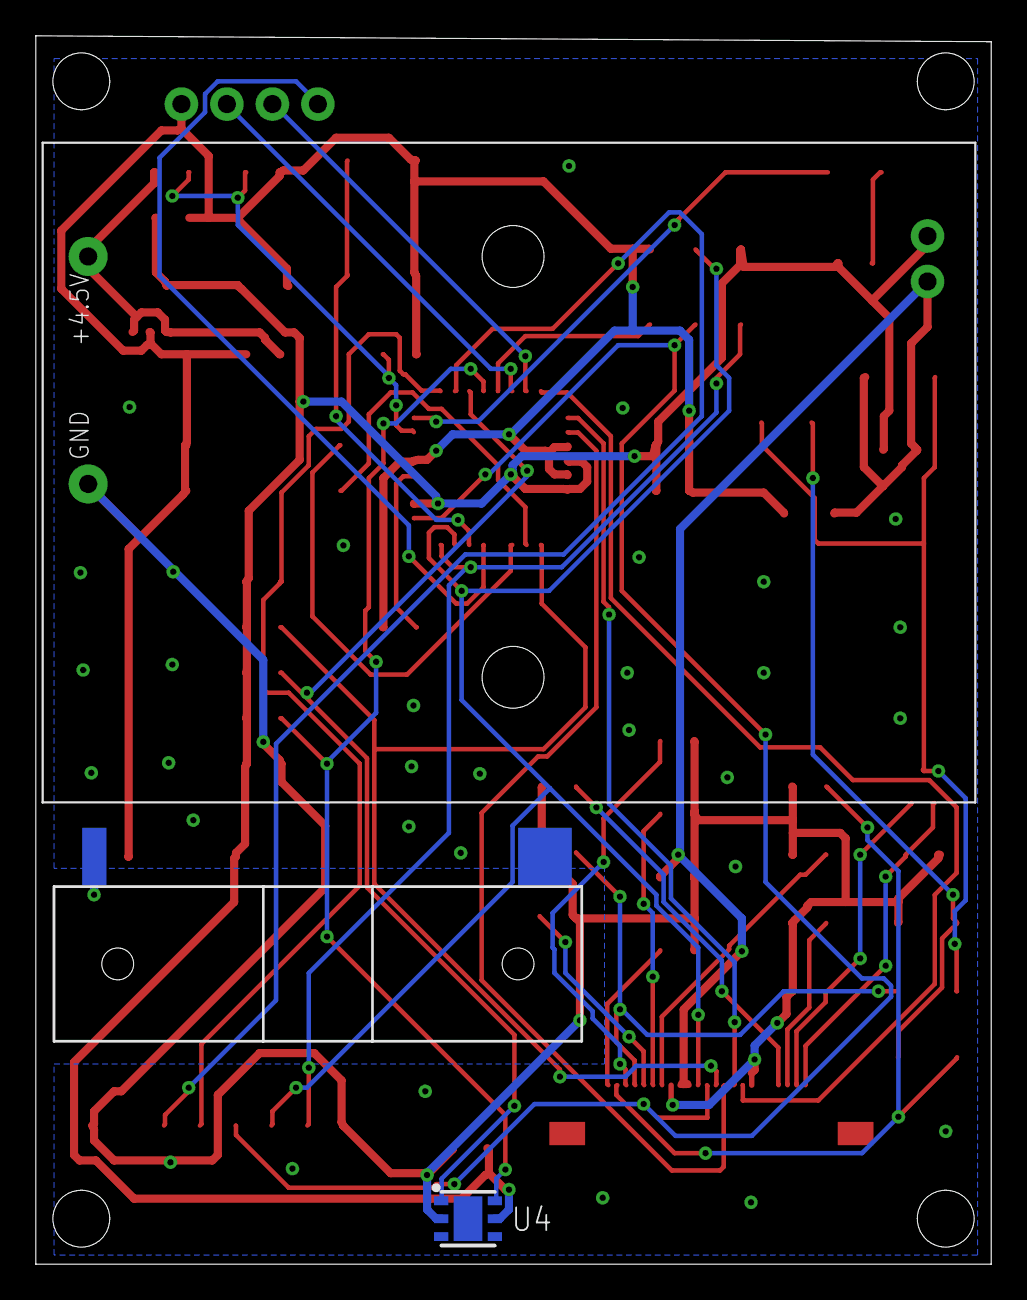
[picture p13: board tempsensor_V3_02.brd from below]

Board: 2 copper layers, 53.3 x 68.6 mm, 49 parts (3 on the bottom side), 40 nets.

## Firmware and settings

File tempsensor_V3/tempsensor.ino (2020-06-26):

/***************************************************************************************************

    Battery-powered remote wireless temperature sensor, version 3

   This is the software for a small (3" x 3" x 1") battery-powered wireless sensor
   that measures temperature and humidity, displays the temperature, date, and time
   on a 1" x 1" e-paper display, and periodically sends data to a receiver that
   digitally simulates the resistance of thermistors inside up to four conventional
   (Mitsubishi) wired thermostats.

   This is version 3, reimplemented with SMD parts optimized for low power consumption,
   because the batteries in the first version only lasted two to three months.
   The objective is to the have 3 AAA batteries (1000 mAH) last a year or more.
   That requires a time-averaged current draw of less than 0.11 mA (110 uA), and
   we achieve about 60-70 uA.

   The custom-built sensor hardware consist of:
   - Atmel ATmega328P 8-bit processor, with 32K of Flash ROM and 2K bytes of RAM
     https://www.microchip.com/wwwproducts/en/ATmega328P
     We use the internal 8Mhz RC oscillator and 8x prescaler, for a 1Mhz clock speed.
   - HopeRF RFM95 LoRa 868/915 Mhz spread-spectrum radio (we use 868 Mhz)
     with a 8mm long omnidirectional helical antenna without a ground plane
     http://www.hoperf.com/rf_transceiver/lora/RFM95W.html
   - Waveshare or Crystalfrontz 1" x 1" 200x200 pixel raw e-Paper display
     https://www.waveshare.com/1.54inch-e-Paper.htm
     https://www.crystalfontz.com/product/cfap200200a10154-200x200-epaper-display
   - Silicon Labs Si7021 I2C digital temperature/humidity sensor
     https://www.silabs.com/documents/public/data-sheets/Si7021-A20.pdf
   - Microchip MCP1711 150 mA ultra-low quiescent current LDO 3.3V regulator
     http://ww1.microchip.com/downloads/en/DeviceDoc/20005415D.pdf
   - 3-cell AAA battery holder
     https://www.digikey.com/product-detail/en/2479/36-2479-ND/303824
   - 2-position slide switch to set the sensor address and mode
     https://www.mouser.com/datasheet/2/96/219-1144706.pdf
   - a pushbutton to cause some debugging info to be displayed
     https://www.ckswitches.com/media/1467/pts525.pdf
   - a 2.1" x 2.7" 2-sided custom printed circuit board, made for $0.50 each by
     https://jlcpcb.com/
   - 3.0" x 3.0" x 1.2" vented plastic enclosure
     Kradex Z123-Wb, https://www.kradex.com.pl/shop

   The design of the hardware and software for the sensors and the corresponding
   receiver is open-source.  See https://github.com/LenShustek/tempsensor.

   Our measured current draw for various phases is as follows:

    sleeping:            13 uA
    get temp/humidity:  4.7 mA for 12 msec
    read battery:       4.5 mA for 0.9 msec
    send packet, 15 dBm: 90 mA for 42 msec
    receive packet:      12 mA for 45 msec
    write date:         4.7 mA for 36 msec (once a day)
    write time:         4.7 mA for 36 msec (once a minute)
    write temp:         4.7 mA for 87 msec (only when it changes)
    update display:     8.2 mA for 360 msec (when any of the above happened)

   The long-term average is about 60 uA if we send a packet about
   every 2 minutes and update the display every minute.
   So the batteries (1000 mAh) should last almost two years.

   The quiescent current of 13 uA is not just the processor, which
   uses about 7 uA with the watchdog timer running. It also includes the
   sleep currents of the e-paper display, RF radio, temperature/humidity
   sensor, battery test voltage divider, and voltage regulator.

   Version 2 used the easier-to-interface Waveshare 1" x 1" display module.
   But the version they are selling now includes a voltage regulator and level 
   shifter so that it works on 5V systems. That makes it useless for this 
   and many other application, since the quiescent current goes from
   less than 5 uA to more than 150 uA! So in V3 we buy the raw e-paper
   display and add the 19 passive components to drive it.

   Tips for programming the "bare" ATMega328P on our PC board:
      - A 2x3 pin header mates to the ISP programmer,
        with the "power board" jumper removed. Red cable at the dot.
        We use the fantastic V2.1 Pololu programmer, set to provide 3.3V power.
        https://www.pololu.com/product/3172
        Select the "Atmel STK500 development board" programmer in the Aduino IDE tools/programmer
        menu, then "Upload using programmer". It takes about 20 seconds.
      - You can use AVRDUDE to check and modify fuse settings if you want to
        change the clocking, or make the clock appear on the CLKO pin.
         avrdude -c stk500v2 -P COM7 -p m328p  (show signature and current fuses)
            avrdude: Device signature = 0x1e950f (probably m328p)
            avrdude: safemode: Fuses OK (E:FF, H:D9, L:62)
        A blank ATMega328p comes with the low fuse preprogrammed as 0x62 to use the
        internal RC 8 Mhz ocillator divided by 8, producing a system clock of 1 Mhz.
        We leave it at that, so we don't normally have to change the fuses.
      - The board selection is "Arduino/Genuino Uno", but the boards.txt file
          (in C:\Users\len\AppData\Local\Arduino15\packages\arduino\hardware\avr\1.6.21\...)
          (may need to uncheck "aggressively cache compiled core" in files/preferences after changing it?)
        has to be changed to allow the frequency to be set to 1 MHz.
          #uno.build.f_cpu=1000000L
          ...
          menu.speed=CPU Speed
          uno.menu.speed.1=1 MHz
          uno.menu.speed.2=2 MHz
          uno.menu.speed.4=4 MHz
          uno.menu.speed.8=8 MHz
          uno.menu.speed.16=16 MHz
          uno.menu.speed.1.build.f_cpu=1000000L
          uno.menu.speed.2.build.f_cpu=2000000L
          uno.menu.speed.4.build.f_cpu=4000000L
          uno.menu.speed.8.build.f_cpu=8000000L
          uno.menu.speed.16.build.f_cpu=16000000L
       (See https://tttapa.github.io/Pages/Arduino/Bootloaders/ATmega328P-custom-frequency.html)

   To output the clock to CLKO (pin 14 on the DIP, pin 12 on the TQFP) so you
   can see with a scope how far off the clock really is from 8 Mhz, change
   the lower fuse byte from the default of 0x62 to 0x22 as follows:
     avrdude -c stk500v2 -p m328p -U lfuse:w:0x22:m
   You can then tweak OSCCAL (as we do in init()) to get closer to 8 Mhz.
   Not that it matters much for us...

   It's harder to figure out what the real frequency of the watchdog timer
   oscillator is, but we did that by looking at how good our timekeeping is
   when we're not getting response packets from the receiver. It's not too
   critical though, since it only affects the accuracy of the time we display
   when out of communication with the central receiver station.

   Tips for debugging:
    - The Pololu programmer includes a USB-to-TTL converter.
      Connect that to a Windows PC and run the Termite terminal emulator,
      then all the Serial.print output will appear when DEBUG is on.
    - Depressing the debug switch when powering on will cause transmissions
      every 5 seconds, instead of every 2 minutes, for antenna testing.
    - Depressing and holding the debug switch during operation will show
      the transmit count, time since last transmit/receive, and receive dB.

   By the way: AVR 8-bit processors like the ATMega328P have no divide
   instruction, so minimize division in places where time matters!

   ------------------------------------------------------------------------------
   Copyright (C) 2015,2018,2020 Len Shustek

   The MIT License (MIT): Permission is hereby granted, free of charge, to any
   person obtaining a copy of this software and associated documentation files
   (the "Software"), to deal in the Software without restriction, including
   without limitation the rights to use, copy, modify, merge, publish, distribute,
   sublicense, and/or sell copies of the Software, and to permit persons to whom
   the Software is furnished to do so, subject to the following conditions:
   The above copyright notice and this permission notice shall be
   included in all copies or substantial portions of the Software.
   THE SOFTWARE IS PROVIDED "AS IS", WITHOUT WARRANTY OF ANY KIND, EXPRESS OR
   IMPLIED, INCLUDING BUT NOT LIMITED TO THE WARRANTIES OF MERCHANTABILITY, FITNESS
   FOR A PARTICULAR PURPOSE AND NONINFRINGEMENT. IN NO EVENT SHALL THE AUTHORS OR
   COPYRIGHT HOLDERS BE LIABLE FOR ANY CLAIM, DAMAGES OR OTHER LIABILITY, WHETHER
   IN AN ACTION OF CONTRACT, TORT OR OTHERWISE, ARISING FROM, OUT OF OR IN
   CONNECTION WITH THE SOFTWARE OR THE USE OR OTHER DEALINGS IN THE SOFTWARE.
   ------------------------------------------------------------------------------
   Change log

   11 Nov 2015, V1.0, L. Shustek, First version.
   30 Nov 2015, V1.1, L. Shustek, Add retry for HC-12 errors.
   19 Dec 2015, V1.2, L. Shustek, Use zone 1..4 in displays.
                                  Read addr switches before going into sleep mode.
   05 Jul 2018, V2.0, L. Shustek, Reimplemented with completely different hardware for lower power.
   12 Oct 2018, V2.1, L. Shustek, Test code for diagnosing possible battery read glitches.
                                  Ignore the first A-to-D conversion after coming out of sleep,
                                  because "the first conversion might give a wrong value" (p250)
                                  might apply to that situation too.
   01 Nov 2018, V2.2, L. Shustek, Well, that doesn't solve the problem; about once every 10 times
                                  we get 3.5-3.7 volts from the A-to-D converter, and I don't know
                                  why. So hack: use the highest of the last 3 values.
   04 Feb 2019, V2.3, L. Shustek, Fix bug: must increment wday when we increment date on our own.
   03 Jan 2020, V2.4, L. Shustek, Display power level compiled in, which is set in
                                  data/projects/Arduino/Libraries/RFradio/RFradio.cpp
                                  Go back to power level 8.
   29 Feb 2020, V2.5, L. Shustek, Display radio version number during initialization.
    2 May 2020, V2.6, L. Shustek, Change to power level 14; the problem with excessive power
                                  consumption is some bad ePaper modules!
    4 Jun 2020, V3.0, L. Shustek, Changes for version 3.0 hardware: raw e-paper display, and SMDs.
                                  Add pushbutton to display debugging stuff.
*****************************************************************************************************/
#define VERSION 30

#define TIME_BETWEEN_SENDS 2*60*1000UL    // Nominally 2 minutes. Should it depend on whether temp changed?
#define TIME_BETWEEN_SENDS_FAST 5*1000UL  // every 5 seconds, for antenna testing

#define DEBUG 0         // output monitor window debugging?
#define MARKTIMING 0    // generate logic analyzer timing pulse output?
#define SLEEPMODE 1     // use processor sleep mode?
#define DO_SEND 1       // send packets?

#define RADIO  1        // is the RF radio module present?
#define EPAPER 1        // is the ePaper display present?
#define TEMPSENSOR 1    // is the temperature sensor present?

#define AREF_MV 3300    // analog reference voltage is VDD = 3.3V

#include <Arduino.h>
#include <Wire.h>       // I2C for Si7021 temperature/humidity sensor
#include <SPI.h>        // SPI for ePaper display, and the RF Radio
#include <RFradio.h>    // our RFM95 LoRa radio library, in the Arduino library directory
#include "display.h"    // e-paper display

// pin assignments

// The #define numbers are the Arduino "fake" pin numbers
#define RF_CS_PIN A2      // RF radio chip select, PC2, PDIP pin 25, TQFP pin 25
#define RF_RESET_PIN A3   // RF radio reset, PC2, PDIP pin 26, TQFP pin 26
#define BATTERY_PIN A0    // battery voltage/2, PC0, PDIP pin 23, TQFP pin 23
#define SW1 6             // node address MSB, PD6, PDIP pin 12, TQFP pin 10
#define SW2 7             // node address LSB, PD7, PDIP pin 13, TQFP pin 11
#define LED A1            // LED, active low, PC1, TQFP pin 24
#define DEBUG_SWITCH 10   // pushbutton, active low, PB2, TQFP pin 14
// The pin assignments for the e-paper display are in display.h!

// The following time marker output is a dedicated output pin:
#define TIME_MARKER_PIN 9   // PB1, PDIP pin 15, TQFP pin 13
#define TIME_MARKER_PORT 0x05  // r/w data port B, 0-based address for SBI/CBI instructions
#define TIME_MARKER_BIT 1      // bit number (not mask)
// The following marker users the TxD pin that is already wired to a header, but is incompatible with DEBUG
//#define TIME_MARKER_PIN 1   // PD1, TQFP pin 31
//#define TIME_MARKER_PORT 0x0b  // r/w data port D, 0-based address for SBI/CBI instructions
//#define TIME_MARKER_BIT 1      // bit number (not mask)


// implicit pins used are:
//    MOSI: arduino pin 11, PB3, PDIP pin 17, TQFP pin 15
//    MISO: arduino pin 12, PB4, PDIP pin 18, TQFP pin 16
//    SCK:  arduino pin 13, PB5, PDIP pin 19, TQFP pin 17
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
void loop (void) {

   #if 0
   // TEMP TEST CODE FOR BATTERY READ FAILURE
   int row = 0;
   unsigned long counter = 1;
   while (1) {
      turnon_ADC();
      analogReference(DEFAULT);  // use the 3.3V reference for battery voltage check
      uint16_t rawv = analogRead(BATTERY_PIN);
      turnoff_ADC();
      byte volts = rawv_to_tenths(rawv);
      if (volts < 40 || counter < 10) { // display a few, then only if battery voltage is too low
         char msg[25];
         turnon_SPI(); dsp_start(false); // partial update mode
         sprintf_P(msg, PSTR("%5lu %d.%1dV"), counter % 100000L, volts / 10, volts % 10);
         dsp_writestr(&font24, 8, row, msg); dsp_displaymem(true);
         dsp_writestr(&font24, 8, row, msg); dsp_displaymem(true);
         row += 24; if (row > 175) row = 0;
         dsp_sleep(); turnoff_SPI(); // put the display into deep sleep
      }
      cpu_sleep(0x03); // 125 msec
      if (++counter % (5000 / 125) == 0) { // flash LED every 5 seconds
         digitalWrite(LED, LOW); delay(200); digitalWrite(LED, HIGH); } }
   #endif

   // check if it is time to read the temperature, send a packet, and get a response

   if (neversent || millis() - last_send_time >= time_between_sends) { // (works ok at overflow)
      xmt_pkt.addr = node_addr;
      xmt_pkt.type = PT_TEMP;
      xmt_pkt.sw_version = VERSION;
      ++xmt_pkt.sequence;

      if (TEMPSENSOR) { //*** read the temperature and humidity
         //MARKTIME(1);
         turnon_TWI();
         Si7021_gettemphum();
         xmt_pkt.temperature = current_temp;
         xmt_pkt.humidity = current_humid;
         turnoff_TWI(); }

      //MARKTIME(2);  //*** read the battery voltage
      turnon_ADC();
      analogReference(DEFAULT);  // use the 3.3V reference for battery voltage check
      uint16_t rawv = analogRead(BATTERY_PIN);
      turnoff_ADC();

      byte batt = rawv_to_tenths(rawv);
      #if DEBUG
      {
         char msg[20];
         sprintf_P(msg, PSTR("V=%d, %d.%dV"), rawv, batt / 10, batt % 10);
         Serial.println(msg); }
      #endif
      xmt_pkt.battery = batt; // use maximum of last three values, b/c occsionally it's bogus
      if (batt_prev > xmt_pkt.battery) xmt_pkt.battery = batt_prev;
      if (batt_prevprev > xmt_pkt.battery) xmt_pkt.battery = batt_prevprev;
      batt_prevprev = batt_prev;
      batt_prev = batt;

      //MARKTIME(3); //*** send the packet
      if (DEBUG) {
         Serial.print("sending at ");
         Serial.println(millis()); }
      if (RADIO && DO_SEND) {
         turnon_SPI();
         RFradio_transmit((byte *)&xmt_pkt, RF_TEMP_PKT_SIZE);
         ++transmit_count;
         //MARKTIME(4); //*** receive the response
         RFradio_receive();
         uint32_t starttime = millis();
         enum RFERR error = RF_UNKNOWN;
         while (1) {  // wait for the response packet
            if (RFradio_gotpkt()) {
               //MARKTIME(5); //*** got the response
               RFRadio_pktstats(&rssi, &snr); // get signal strength and signal-to-noise ratio
               error = RFradio_getpkt((byte *)&rcv_pkt, RF_RESP_PKT_SIZE);
               if (error == RF_OK) {
                  datetime_now = rcv_pkt.datetime;  // copy the packet's datetime
                  datetime_now_update_time = last_rcv_time = millis();
                  datetime_now_millis = 0; }
               else {
                  //MARKTIME(5);
                  //MARKTIME(error);
                  // do something to display the receive packet error?
               }
               break; }
            if (millis() - starttime > 75) { // msec to wait for packet
               //MARKTIME(5);
               //MARKTIME(RF_NOPKT);
               // do something to display lack of response packet?
               break; } //
         }
         RFradio_sleep();
         turnoff_SPI(); }
      last_send_time = millis();
      neversent = false; //
   } // send

   // check if we need to update the display because the minute changed

   update_time();
   if (datetime_now.min != displayed_min) {
      //uint32_t dsp_update_start = millis(); //TEMP
      displayed_min = datetime_now.min; // the minute has changed
      MARKTIME(1);  //*** write updated date/time/temp
      turnon_SPI();
      dsp_start(false); // partial update mode
      if (datetime_now.date != displayed_date) // only write date if changed
         datechange_countdown = 2;
      if (datechange_countdown) { // but do it twice, for both display pages
         writedate(&datetime_now); // write day and date
         displayed_date = datetime_now.date;
         --datechange_countdown; }
      writetime(&datetime_now); // always write time
      if (current_temp != displayed_temp) // only write temp if changed
         tempchange_countdown = 2;
      if (tempchange_countdown) { // but do it twice, for both display pages
         char msg[25];
         sprintf_P(msg, PSTR("%2d`"), min(current_temp, 99));
         dsp_writestr(&font67, 16, 40, msg);  // write temperature
         displayed_temp = current_temp;
         --tempchange_countdown; }
      MARKTIME(2); //*** update the display
      //uint32_t dsp_showmem_start = millis(); //TEMP
      dsp_displaymem(true);
      MARKTIME(3);
      dsp_sleep(); // put the display into deep sleep
      turnoff_SPI();
      MARKTIME(4);
      //uint32_t dsp_update_end = millis(); //TEMP
      //Serial.print("dsp times: "); Serial.print(dsp_update_end - dsp_update_start);
      //Serial.print(' '); Serial.println(dsp_update_end - dsp_showmem_start);  //TEMP
   }

   if (digitalRead(DEBUG_SWITCH) == 0)  // check if debug button is pushed
      show_debug_info();

   // figure out how long we should sleep for

   uint32_t time_to_next_minute_change = (60 - datetime_now.sec) * 1000U;
   //Serial.print("now sec "); Serial.print(datetime_now.sec); //TEMP
   //Serial.print(" next min "); Serial.println(time_to_next_minute_change); // TEMP

   uint32_t time_since_last_send = millis() - last_send_time;
   // Think twice if you have a plan for how to simplify this calculation!
   uint32_t time_to_next_send;
   if (time_since_last_send >= time_between_sends)
      time_to_next_send = 0;
   else time_to_next_send = time_between_sends - time_since_last_send;

   uint16_t sleep_time = min(time_to_next_send, time_to_next_minute_change);

   #if DEBUG
   Serial.print(time_to_next_send); Serial.print(" nxt snd, nxt min: "); Serial.println(time_to_next_minute_change);
   #endif

   // The watchdog oscillator tends to run slow! Table 35-10 on page 605, and
   // our measurements, show that at 20C and 3.3V it typically is 118-124 Khz
   // instead of 128 Khz, or 6-7% slow. That matters when we're not getting
   // frequent clock updates from the receiver, since we have to adjust for
   // the time during sleep when TIMER0 is not running. We thus adjust our
   // sleep time numbers with the WD macro so that we're closer to real time.

   #if SLEEPMODE
#define WDSPEED 122  // typical speed of watchdog oscillator in Khz
#define WD(x) (uint16_t)((uint32_t)x*128/WDSPEED)

   byte sleep_code; // WDP3, WDP2, WDP1, WDP0, but not in consecutive bits!
   if (sleep_time >= WD(8000)) {
      sleep_code = 0x21;  // 8 seconds is the most the processor can sleep
      sleep_time = WD(8000); }
   else if (sleep_time >= WD(4000)) {
      sleep_code = 0x20;  // 4 seconds
      sleep_time = WD(4000); }
   else if (sleep_time >= WD(2000)) {
      sleep_code = 0x07;  // 2 seconds
      sleep_time = WD(2000); }
   else if (sleep_time >= WD(1000)) {
      sleep_code = 0x06;  // 1 seconds
      sleep_time = WD(1000); }
   else if (sleep_time >= WD(500)) {
      sleep_code = 0x05;  // 0.5 seconds
      sleep_time = WD(500); }
   else if (sleep_time >= WD(250)) {
      sleep_code = 0x04;  // 0.25 seconds
      sleep_time = WD(250); }
   else if (sleep_time >= WD(125)) {
      sleep_code = 0x03;   // 0.125 sec
      sleep_time = WD(125); }
   else if (sleep_time >= WD(64)) {
      sleep_code = 0x02;   // 64 msec
      sleep_time = WD(64); }
   else if (sleep_time >= WD(32)) {
      sleep_code = 0x01;   // 32 msec
      sleep_time = WD(32); }
   else
      sleep_code = 0;   // don't sleep for less than that; just delay
   #endif //SLEEPMODE

   //MARKTIME(8); //*** sleep
   #if SLEEPMODE
   if (sleep_code == 0)
      delay(sleep_time);  // delay instead of sleeping
   else {
      cpu_sleep(sleep_code);  // "deep sleep" hibernation; only the watchdog timer runs
      noInterrupts (); {
         extern volatile uint32_t timer0_millis;
         timer0_millis += sleep_time; // approximate adjustment to the clock, which was stopped
         interrupts(); } }
   #else
   delay(sleep_time);
   #endif

   //MARKTIME(9); //*** wake up
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

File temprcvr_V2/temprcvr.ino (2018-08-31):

/**************************************************************************************

    remote temperature receiver

   This software is inside a box that receives wireless data from four remote
   temperature sensors. We replaces the thermistors in our Mitsubishi PAR-21MAA
   thermostats with a digitally-generated resistance that reflects the
   temperature at the remote locations.

   The custom-built hardware for the receiver consists of the following:
   - Teensy 3.1 microcontroller from http://www.pjrc.com
   - HopeRF RFM95 LoRa 868/915 Mhz spread-spectrum radio
     http://www.hoperf.com/rf_transceiver/lora/RFM95W.html
   - four Microchip MCP4251-series 50K digital potentiometers
     https://www.microchip.com/wwwproducts/en/MCP4251
   - 4-line by 20-character LCD display
     https://www.adafruit.com/product/198
   - Chronodot realtime clock with DS3231 and CR1632 3V battery
     http://docs.macetech.com/doku.php/chronodot_v2.0
   - a piezo-electric buzzer for making low-battery alarm chirps
   - two pushbutton switches
   - three mode-setting slide switches (currently unused)

   The four lines of the display are used as follows:
    line 1:  titles of the four zones
    line 2:  current zone temperatures
    line 3:  current humidity, or remote sensor battery status "LoBat"
    line 4:  the current date and time, alternating with various
             statistical and debugging information

   The design of the hardware and software for this receiver and the corresponding
   sensors is open-source.  See https://github.com/LenShustek/tempsensor.

   -------------------------------------------------------------------------------
    (C) Copyright 2015,2018 Len Shustek
   The MIT License (MIT): Permission is hereby granted, free of charge, to any
   person obtaining a copy of this software and associated documentation files
   (the "Software"), to deal in the Software without restriction, including
   without limitation the rights to use, copy, modify, merge, publish, distribute,
   sublicense, and/or sell copies of the Software, and to permit persons to whom
   the Software is furnished to do so, subject to the following conditions:
   The above copyright notice and this permission notice shall be
   included in all copies or substantial portions of the Software.
   THE SOFTWARE IS PROVIDED "AS IS", WITHOUT WARRANTY OF ANY KIND, EXPRESS OR
   IMPLIED, INCLUDING BUT NOT LIMITED TO THE WARRANTIES OF MERCHANTABILITY, FITNESS
   FOR A PARTICULAR PURPOSE AND NONINFRINGEMENT. IN NO EVENT SHALL THE AUTHORS OR
   COPYRIGHT HOLDERS BE LIABLE FOR ANY CLAIM, DAMAGES OR OTHER LIABILITY, WHETHER
   IN AN ACTION OF CONTRACT, TORT OR OTHERWISE, ARISING FROM, OUT OF OR IN
   CONNECTION WITH THE SOFTWARE OR THE USE OR OTHER DEALINGS IN THE SOFTWARE.
   -------------------------------------------------------------------------------
   Change log

   11 Nov 2015, V1.0, L. Shustek; first version
   29 Nov 2015, V1.1, L. Shustek; add pushbutton commands
   14 Dec 2015, V1.2, L. Shustek; change zone number displays to be 1..4
    8 Jan 2016, V1.3, L. Shustek; expect transmissions only every 30 seconds
    9 Jan 2016, V1.4. L. Shustek; use packet sequence numbers to tally lost packets
   30 Jan 2016, V1.5, L. Shustek; better condensed packet count display
   29 Feb 2016, v1.6, L. Shustek; add humidity display, and button for holding display
   15 Oct 2016, V1.7, L. Shustek; expect and display sensors' software version number;
                                  longer comm delay threshold for new temp send 1/minute
   8 Aug 2018,  V2.0, L. Shustek; change to use LoRa radio for the new temperature
                                  sensors, and add signal strength display in dBm
*/

#define VERSION "2.0"
#define BATTERY_THRESHOLD 38     // minimum good battery level in tenths of a volt
#define DEBUG 0
#define TESTS 0

#define LOST_COMM_TIME (4*60+20) // 4+ minutes before declaring a zone "lost"

#include <arduino.h>
#include <LiquidCrystal.h>  // for LCD display
#include <SPI.h>            // for the digital pots and the RF LoRa radio using SPI
#include <Wire.h>           // for the realtime clock using I2C
#include <RFradio.h>        // our RFM95 LoRa radio library
#include "IntervalTimer.h"  // for timing

// pin assignments

#define SPEAKER_POS 20    // bipolar speaker pin
#define SPEAKER_NEG 21    // bipolar speaker pin
#define RF_CS 4           // RF radio chip select pin
#define RF_RESET 22       // RF radio reset pin
#define MODESW_1 23       // mode slide switch pin
#define MODESW_2 16       // mode slide switch pin
#define MODESW_3 17       // mode slide switch pin
#define BUTTON_1 2        // action pushbutton pin, which is normally closed
#define BUTTON_2 3        // action pushbutton pin, which is normally closed
#define BUTTON_PUSHED 1
#define BUTTON_NOT_PUSHED 0
#define SPI_MOSI 11       // default SPI pins for pots and RF radio
#define SPI_MISO 12       // default SPI pins for pots and RF radio
#define SPI_CLK 13        // default SPI pins for pots and RF radio
#define LED 13            // (SPI_CLK is also connected to the onboard LED)
#define SPI_CS1 14        // select pin for the first two pots, IC U$2
#define SPI_CS2 15        // select pin for second two pots, IC U$4
LiquidCrystal lcd(/*RS*/ 5, /*E*/ 6, /*D4-D7*/ 7, 8, 9, 10);  // LCD pins

unsigned long malformed_packets = 0;

struct { // current information about each zone
   const char *name;
   byte temperature;
   byte battery;
   byte humidity;
   bool lost_comm; // did we lose communication?
   uint32_t last_sequence;
   unsigned long good_packets;
   unsigned long bad_packets;
   unsigned long missed_packets;
   unsigned long msec_since_packet;
   int8_t rssi; // last signal strength
   int8_t snr;  // last signal-to-noise ratio
   byte sw_version; }
zone[4];

bool refresh_zoneinfo = false;    // do we need to refresh zone info display on rows 1 and 2?

struct datetime_t
   timenow, // current time
   clock_init = { // when we first wrote the code
   50, 10, 8, 4, 8, 8, 48 };

static const char *months[] = {
   // index 1..12 from realtime clock
   "xxx", "Jan", "Feb", "Mar", "Apr", "May", "Jun", "Jul", "Aug", "Sep", "Oct", "Nov", "Dec"};
static const byte days_in_month []  = {
   // index 1..12 from realtime clock
   99, 31, 28, 31, 30, 31, 30, 31, 31, 30, 31, 30, 31 };

#define PACKETLOG_SIZE 100
struct { // the log of incoming packets we record for debugging
   byte addr; // 0..3
   byte temperature;
   byte battery;
   struct datetime_t timestamp; } packet_log[PACKETLOG_SIZE];
int packetlog_count = 0; // number of events stored
int packetlog_index = 0; // next log array location to write

#define ERRORLOG_SIZE 25
struct { // the log of errors we record for debugging
   byte addr;   // currently we only store "disconnect" events
   struct datetime_t timestamp; } error_log[ERRORLOG_SIZE];
int errorlog_count = 0; // number of errors stored
int errorlog_index = 0; // next log array location to write
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

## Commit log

2015-12-02 photo of remote temperature sensor
2015-12-02 schematic of receiver
2015-12-02 source code for remote temp sensor
2015-12-02 schematic of temperature sensor
2015-12-02 PC board layout of temperature sensor
2015-12-24 source code for remote temperature sensor
2018-08-31 Version 2: lower power for better battery life
2019-02-04 Update tempsensor.ino
    Fix date update bug
    [tempsensor.ino]
2020-06-26 version 3 of temperature sensor
    [parts.xlsx, tempsensor_V3_02.brd, tempsensor_V3_02.sch]

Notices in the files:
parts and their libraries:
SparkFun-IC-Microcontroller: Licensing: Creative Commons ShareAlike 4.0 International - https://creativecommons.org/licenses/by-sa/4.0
